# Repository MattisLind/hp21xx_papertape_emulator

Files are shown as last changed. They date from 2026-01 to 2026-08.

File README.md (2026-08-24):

# HP 21XX Paper Tape Emulator

The idea to this project come from this page: [newton.freehostia.com/hp](https://newton.freehostia.com/hp/). A simple PIC processor connected to the ubiquitous HP 12566 Microcircuit boards that provide 16 bits of general input and output with a simple handshake. The software interface is identical to the one used for the paper tape reader and paper tape punch. The interface originally used for punch and reader, 12597A is a +12V level interface which made them a bit harder to interface. The 12566A board which used just standard +5V signals was easier to work with and I had plenty of them.

So I thought I should make my own, but then I thought, why involve a PC. I could store the files I wished to download on a small SD-card and have a small display and a couple of buttons to interact with to select what file I wanted to download into the machine! And then there was this idea, why not make it work as a punch as well so that I can take the output from the HP computer and store it on a file that subsequently can be uploaded. Useful if one would try compiling some small program on it.

## Progress

Now I am able to both read files into the computer and punch from the computer. Here is a quick video showing when a Chess program is loaded into my HP 2100S.

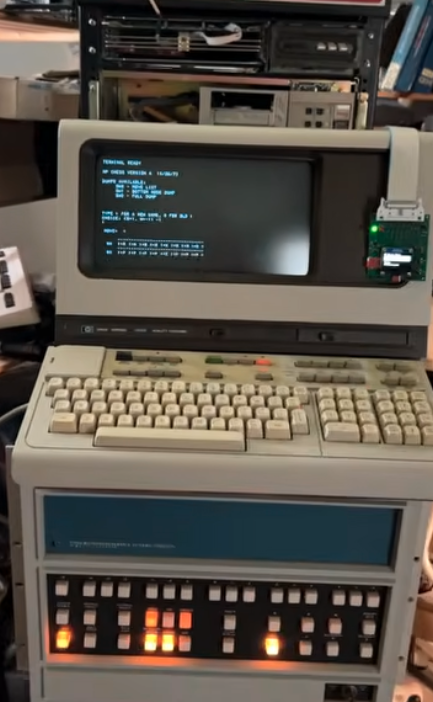
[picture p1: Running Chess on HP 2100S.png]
Watch the video (https://www.youtube.com/shorts/xUi1qgBoRDE)


Loading of the 72 k abolute binary files takes place when the red LED light up for a few seconds. It fills up the entire 32k Word memory space of the HP 2100.

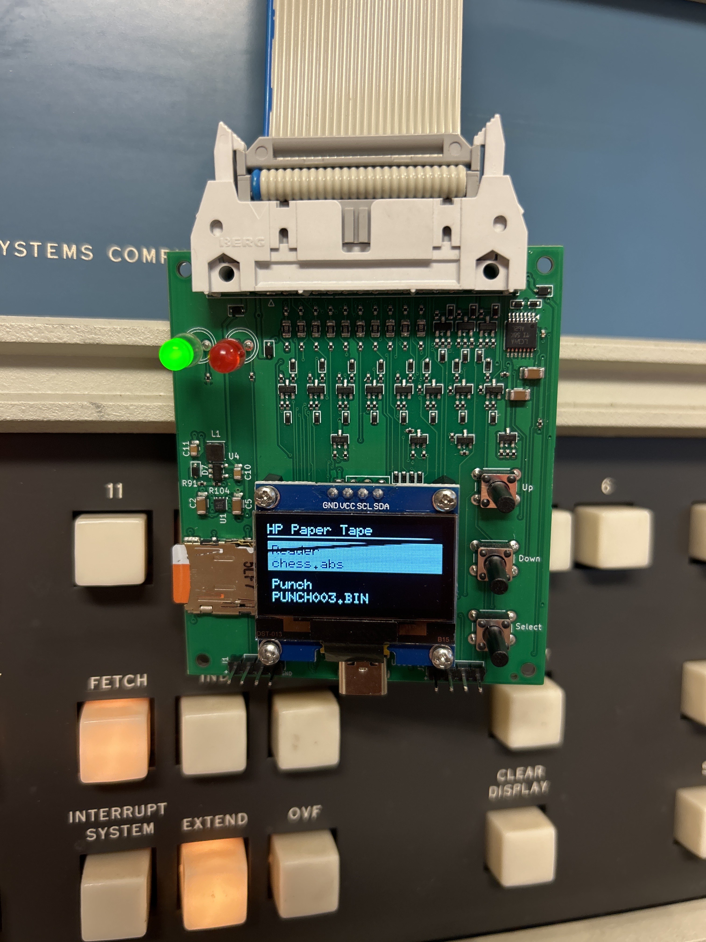
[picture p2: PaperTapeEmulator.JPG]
picture of the gadget


This is how the finished board came to look like. Three buttons, Up, Down and Select, and small 128x64 OLED panel to configure and control it. A Micro SD card for file storage and USB-C connector that can be used to power the device unless powered over the 26 pin ribbin connector. The green LED indicate power and the red LED indicate activity.

The UI is rather simple. Simply navigating up and down and press the select button. The main menu have two menu items, one to select the reader file and one select the punch file. Pressing select will get you to a file selct menu where the currently selected file is shown and where you can navigate to the file you want to select. Pressing select also exits back to the main menu. On the punch menu there are also an option to create a new file with a sequence number. If an existing file is selected it will append to that file.

Since there are only three buttons the UI also have special actions when pressing a button more than 4 seconds. A long press on the select menu brings up the configuration menu. In here you can set if signals are active high or active low. For 12566A and 12566B there are two board revsions which get you to choose from active high (POS TRUE) or active low (GND TRUE) data. The active high or low for hand shake signals are configurable on both these cards. The 12566C has all parameters configurable. You should check yoour board so that it matches the config you set in this menu. There is also an option to configure 12V signals or 5V signals. 5V is used for 12566 boards while 12V is used for 12597 boards. You cannot mix a 12566 board and a 12566 board and connect them simultaneously to the paper tape emulator. There are also certain variants of the 12597 board that have -12V signals. This type of board is not supported. Unless you convert the board to +12V.

If you long press on the Down button when in the main menu the currently selected file will be rewound to the beginning so that it can be read again.

If you long press on the Up button the USB MSC mode will be stated and all emulation is stopped. This will allow you to browse the contents from a host computer if the emulator is connected over USB-C. This feature is now active. The STM32F103 have a very small memory and it will take a while for the MCU to transfer big amounts to the host. Unfortunately it seems like at least Windows 10 wants to read about 16000 blocks from the disk when it is mounted. This takes quite some time and will ead to that the drive is not showing up active in the computer. Probably because the file system is 8Gb. I think that by making the partition smaller it will read less from the disk when moounting it. A 32 Meg partition will easily hold all the paper tapes you ever will use on a HP21xx machine.

## BOM

For all the surface mount components the BOM is among the production files in the kicad folder. Other than that the following hardware is needed to complete the emulator:

* [Screws  M2 5mm.  8 pcs](https://www.aliexpress.com/item/32768907028.html)
* [Nylon hex standoffs for the display are 6mm M2. 4 pcs](https://www.aliexpress.com/item/1005003577479911.html)
* [Nylon washers M2 5mm x 1mm high: 8 pcs.](https://www.aliexpress.com/item/1005008318320472.html)
* [Display is a OLED 128x64 with I2C Using SH1106 chip.](https://www.aliexpress.com/item/1005007451015054.html)
* [Buttons are 6x6 mm 13 mm high tactile buttons](https://www.aliexpress.com/item/1005002487399422.html)
* [Connector is Ampehnol FCI 71922-126LF](https://www.mouser.se/ProductDetail/649-71922-126LF)
* Red 5 mm LED
* Green 5 mm LED
* 4 pin header 2.54 mm for SWD and serial debugging port. 2 pcs.

## Connecting it to the HP machine 

The connector for the HP computer is a 48 pin 0.156 inch (3.96 mm) connector. EDAC and Sullins manufacture these.

I used a 26 pin ribbon connector in the emulator end and splitted that one in two 13 conductor halves going to one each 48 pin connector.

### Mods to supply 5V to the emulator

A good idea is to modify the 12566 and 12597 boards to supply 5V to the emulator. There are schottky diodes on the supply line internally on the emulator to avoid backpowering things so it should be safe to connect the punch and reader to different computers and also safe to have a PC connected to the USB simultaneously.

I modifed my 12566 boards to supply 5V on pin 20 since it is unused also on the 12597 boards this pin is unused.

### Reader
|Pin on 26 pin connector | Designator on the 26 pin connector | Pin on 48 pin connector for the 12566 board |HP designator on 12566 board | Pin on the 48 pin connector for the 12597 board | HP designator on 12597 board |
|----|-----|-----|----|----|----|
| 14 | NC  | NA  | NA | | |
| 15 | INCR | 22 |  DEVICE COMMAND  | AA  | Read |
| 16 | OUTFR | 23 | DEVICE FLAG | 23 | Feed Hole |
| 17 | OUT7 | 8  | Bit 7 | 8 | Bit 7 | 
| 18 | OUT6 | 7  | Bit 6 | 7 | Bit 6 |
| 19 | OUT5 | 6  | Bit 5 | 6 | Bit 5 | 
| 20 | OUT4 | 5  | Bit 4 | 5 | Bit 4 |
| 21 | OUT3 | 4  | Bit 3 | 4 | Bit 3 |
| 22 | OUT2 | 3  | Bit 2 | 3 | Bit 2 |
| 23 | OUT1 | 2  | Bit 1 | 2 | Bit 1 |
| 24 | OUT0 | 1  | Bit 0 | 1 | Bit 0 |
| 25 | GND  | 24 | Ground | 24 | Ground |
| 26 | +5V  | 20 | | 20 |  |

### Punch

Please note that the table below has been updated since I found errors in the table. If you built this cable already, please doublecheck the cable!

|Pin on 26 pin connector | Designator on the 26 pin connector | Pin on 48 pin connector for the 12566 board | HP designator on 12566 board |Pin on the 48 pin connector for the 12597 board | HP designator on 12597 board| 
|----|-----|-----|----|----|----|
| 1  | +5V | 20  | | 20 |  |
| 2  | GND | 24  | GROUND | 24 | Ground |
| 3  | IN0  | A  | BIT 0 | A  | Bit 0 |
| 4  | IN1  | B  | BIT 1 | B  | Bit 1 |
| 5  | IN2  | C  | BIT 2 | C  | Bit 2|
| 6  | IN3  | D  | BIT 3 | D  | Bit 3 |
| 7  | IN4  | E  | BIT 4 | E  | Bit 4 |
| 8  | IN5  | F  | BIT 5 | F | Bit 5 |
| 9 | IN6  | H  | BIT 6 | H  | Bit 6 |
| 10 | IN7 | J | BIT 7 | J | Bit 7 |
| 11  | OUTFP| 23 | DEVICE FLAG | 23 | Flag |
| 12  | INCP | 22  | DEVICE COMMAND | AA | Punch |
| 13 | PAPER_LOW | 6 | BIT 5 | 6 | Low Tape|

## Firmware

The firmware is built using the Arduino framework. <strike>I have been using the Maple based core adapted by Roger Clark: [Arduino_STM32](https://github.com/rogerclarkmelbourne/arduino_stm32). Follow the instructins and install this in your Arduino Environment.
In addition to that I have replaced the standard SDfat V2 library with a SDfat library that works with this core, [SDFat library by VictorPV](https://github.com/victorpv/SdFat), but still support long file names.

Then it is important to select this core under tools. Also select the correct target, STM32F103C8.</strike>

I now converted into using the standard core for STM32 on Arduino. The TinyUSB library has to be installed. In addition to that I downloaded and installed [TinyUSB-Arduino-STM32](https://github.com/code-fiasco/TinyUSB-Arduino-STM32?utm_source=chatgpt.com) for STM32 support. Please follow instructions in the repo.

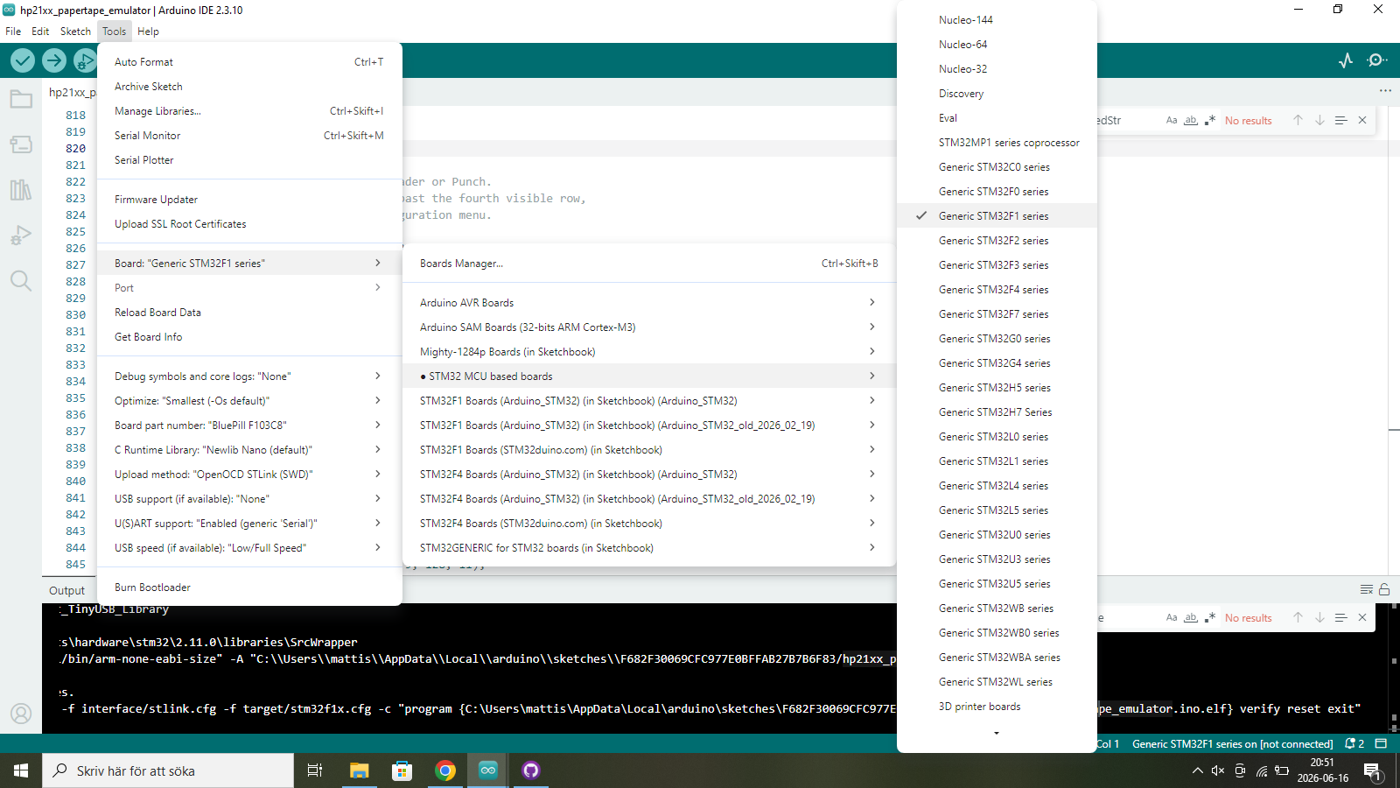
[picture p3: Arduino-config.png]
config


The picture above indicate the config needed. STM32F103 Bluepill. Please adapt dependning on download method. In the binaries folder there is a new binary that can be used directly.

Uploading takes place over SWD so a STM32 SWD dongle is required. Unfortunately there are no jumpers available on the board to allow download over the serial port. It can be patched. The BOOT0 pin is pulled down with a 10k resistor to ground but can be tied to +3.3V to achieve a high input. BOOT1/PB2 is currently in use as an output, PUSEL, which alread has a pull down to ground already. Jumpering BOOT0 like this would then allow to enter serial boot mode after reset. There is also no reset button so either a power cycle is required or attach an external button to the RESET input of the processor. Future version might add a BOOT0 jumper.

A new layout has been comitted to the repo that adds a jumper that allow setting BOOT0 high. Along with BOOT1 pulled low this will then let the MCU enter serial download mode.

Software to upload code via serial port is for example [stm32flash](https://github.com/FYSETC/stm32flash)

I have not tried serial boot mode myself so I cannot tell how to work with it. I always use the STM32 SWD dongle.

## Documentation

Here are some links to relevant HP document for the 12597 and 12566 boards:

* [12566B Micro circuit interface manual](https://bitsavers.org/pdf/hp/21xx/interfaces/12566.pdf)
* [12597A-002 Reader interface manual](https://www.bitsavers.org/pdf/hp/21xx/interfaces/12597A-002.pdf)
* [12597A-005 Punch interface manual](https://www.bitsavers.org/pdf/hp/21xx/interfaces/12597A-005.pdf)

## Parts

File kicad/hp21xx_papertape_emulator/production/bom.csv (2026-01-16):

Designator | Footprint | Quantity | Value | LCSC Part #
BRD1 | PinHeader_1x04_P2.54mm_Vertical | 1 | SSD1306
C1, C3 | 0402 | 2 | 20p | C1554
C10, C4, C6, C7, C8, C9 | 0402 | 6 | 100n | C1525
C2, C5 | 1206 | 2 | 4.7u | C29823
D1 | LED_D5.0mm | 1 | LED
D2 | LED_D5.0mm | 1 | 3.3V PWR
D3, D4 | D_SOD-323 | 2 | 1N5819WS | C191023
J1 | PinHeader_1x04_P2.54mm_Vertical | 1 | SWD
J2 | PinHeader_1x04_P2.54mm_Vertical | 1 | SERIAL
J3 | microSD_HC_Hirose_DM3AT-SF-PEJM5 | 1 | Micro_SD_Card_Det_Hirose_DM3AT
J4 | IDC-Header_2x10_P2.54mm_Latch_Horizontal | 1 | HP Microcircuit
R1, R2 | 0402 | 2 | 2k | C4109
R10, R26 | 0402 | 2 | 100k | C25741
R11, R13, R15, R17, R24, R27, R33, R35, R37 | 0402 | 9 | 330 | C25104
R12, R14, R16, R18, R25, R28, R34, R36, R38 | 0402 | 9 | 820 | C3015788
R19, R20, R21, R22, R23, R29, R30, R31, R32 | 0402 | 9 | 220 | C25091
R3, R4 | 0402 | 2 | 510 | C25123
R39 | 0603 | 1 | 1.8k | C4177
R40 | 0402 | 1 | 3.3k | C25890
R5 | 0402 | 1 | 1.5k | C25867
R6, R7 | 0402 | 2 | 22 | C25092
R8, R9 | 0402 | 2 | 5.1k | C25905
SW1 | SW_PUSH_6mm_H13mm | 1 | Select
SW2 | SW_PUSH_6mm_H13mm | 1 | Up
SW3 | SW_PUSH_6mm_H13mm | 1 | Down
U1 | WSON-6-1EP_2x2mm_P0.65mm_EP1x1.6mm | 1 | TLV75533PDRV | C2861750
U2 | LQFP-48_7x7mm_P0.5mm | 1 | STM32F103C8Tx | C8734
U3 | SOT-23-6 | 1 | USBLC6-2SC6 | C21713975
U4 | SOT-353_SC-70-5 | 1 | 74AHC1GU04 | C460485
U5 | TSSOP-20_4.4x6.5mm_P0.65mm | 1 | 74HCT245 | C6779
U6 | SOT-23-5 | 1 | 74LVC1G04 | C7827
U7 | TSSOP-20_4.4x6.5mm_P0.65mm | 1 | 74LVC245 | C7848
USB1 | HRO-TYPE-C-31-M-12 | 1 | HRO-TYPE-C-31-M-12 | C165948
Y1 | Crystal_SMD_5032-2Pin_5.0x3.2mm | 1 | 8MHz | C115962

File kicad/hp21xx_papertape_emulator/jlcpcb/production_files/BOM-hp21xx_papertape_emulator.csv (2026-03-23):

Comment | Designator | Footprint | LCSC | Quantity
1.5k | R5 | R_0402_1005Metric | C25867 | 1
1.8k | R39 | R_0603_1608Metric | C4177 | 1
100 | R10,R47,R48,R54,R57,R60,R63,R66,R69,R72,R75,R78,R81,R86,R88 | R_0402_1005Metric | C25076 | 15
100k | R19,R26,R55,R58,R61,R64,R67,R70,R73,R76,R79,R82,R85,R89,R93 | R_0402_1005Metric | C25741 | 15
100n | C4,C6,C7,C8,C9 | C_0402_1005Metric | C1525 | 5
10k | R1,R104,R2,R45,R49,R50,R51,R52,R56,R59,R62,R65,R68,R71,R74,R77,R80,R83 | R_0402_1005Metric | C25744 | 18
10uH | L1 | L_Sunlord_SWPA3010S | C2049730 | 1
1N5819WS | D3,D4,D5,D6,D7 | D_SOD-323 | C191023 | 5
1k | R100,R101,R102,R103,R12,R14,R16,R18,R25,R28,R34,R36,R38,R42,R46,R87,R94,R95,R96,R97,R98,R99 | R_0402_1005Metric | C11702 | 22
1u | C10,C11 | C_0805_2012Metric | C28323 | 2
20p | C1,C3 | C_0402_1005Metric | C1554 | 2
22 | R6,R7 | R_0402_1005Metric | C25092 | 2
220 | R20,R21,R22,R23,R29,R30,R31,R32,R43,R44 | R_0402_1005Metric | C25091 | 10
3.3k | R40 | R_0402_1005Metric | C25890 | 1
330 | R11,R13,R15,R17,R24,R27,R33,R35,R37,R41 | R_0805_2012Metric | C17630 | 10
4.7u | C12,C13,C2,C5 | C_1206_3216Metric | C29823 | 4
5.1k | R8,R9 | R_0402_1005Metric | C25905 | 2
510 | R3,R4 | R_0402_1005Metric | C25123 | 2
74LVC14 | U6 | TSSOP-14_4.4x5mm_P0.65mm | C7663 | 1
74LVC245 | U7 | TSSOP-20_4.4x6.5mm_P0.65mm | C7848 | 1
86.6k | R91 | R_0402_1005Metric | C19709 | 1
8MHz | Y1 | Crystal_SMD_5032-2Pin_5.0x3.2mm | C115962 | 1
AP3012 | U4 | SOT-23-5 | C102618 | 1
BAT54J | D10,D11,D12,D13,D14,D15,D16,D17,D18,D19,D20,D21,D22,D23,D24,D25,D26,D27,D28,D29,D8,D9 | D_SOD-523 | C51315114 | 22
BSS138 | Q1,Q10,Q11,Q13,Q14,Q2,Q3,Q4,Q5,Q6,Q7,Q8,Q9 | SOT-23 | C53113928 | 13
BSS84 | Q12,Q15 | SOT-23 | C82079 | 2
BZX584B5V1 | D30,D31,D32,D33,D34,D35,D36,D37,D38,D39 | D_SOD-523 | C968173 | 10
HRO-TYPE-C-31-M-12 | USB1 | HRO-TYPE-C-31-M-12 | C165948 | 1
Micro_SD_Card_Det_Hirose_DM3AT | J3 | microSD_HC_Hirose_DM3AT-SF-PEJM5 | C114218 | 1
STM32F103C8Tx | U2 | LQFP-48_7x7mm_P0.5mm | C8734 | 1
TLV75533PDRV | U1 | WSON-6-1EP_2x2mm_P0.65mm_EP1x1.6mm | C2861750 | 1
USBLC6-2SC6 | U3 | SOT-23-6 | C21713975 | 1

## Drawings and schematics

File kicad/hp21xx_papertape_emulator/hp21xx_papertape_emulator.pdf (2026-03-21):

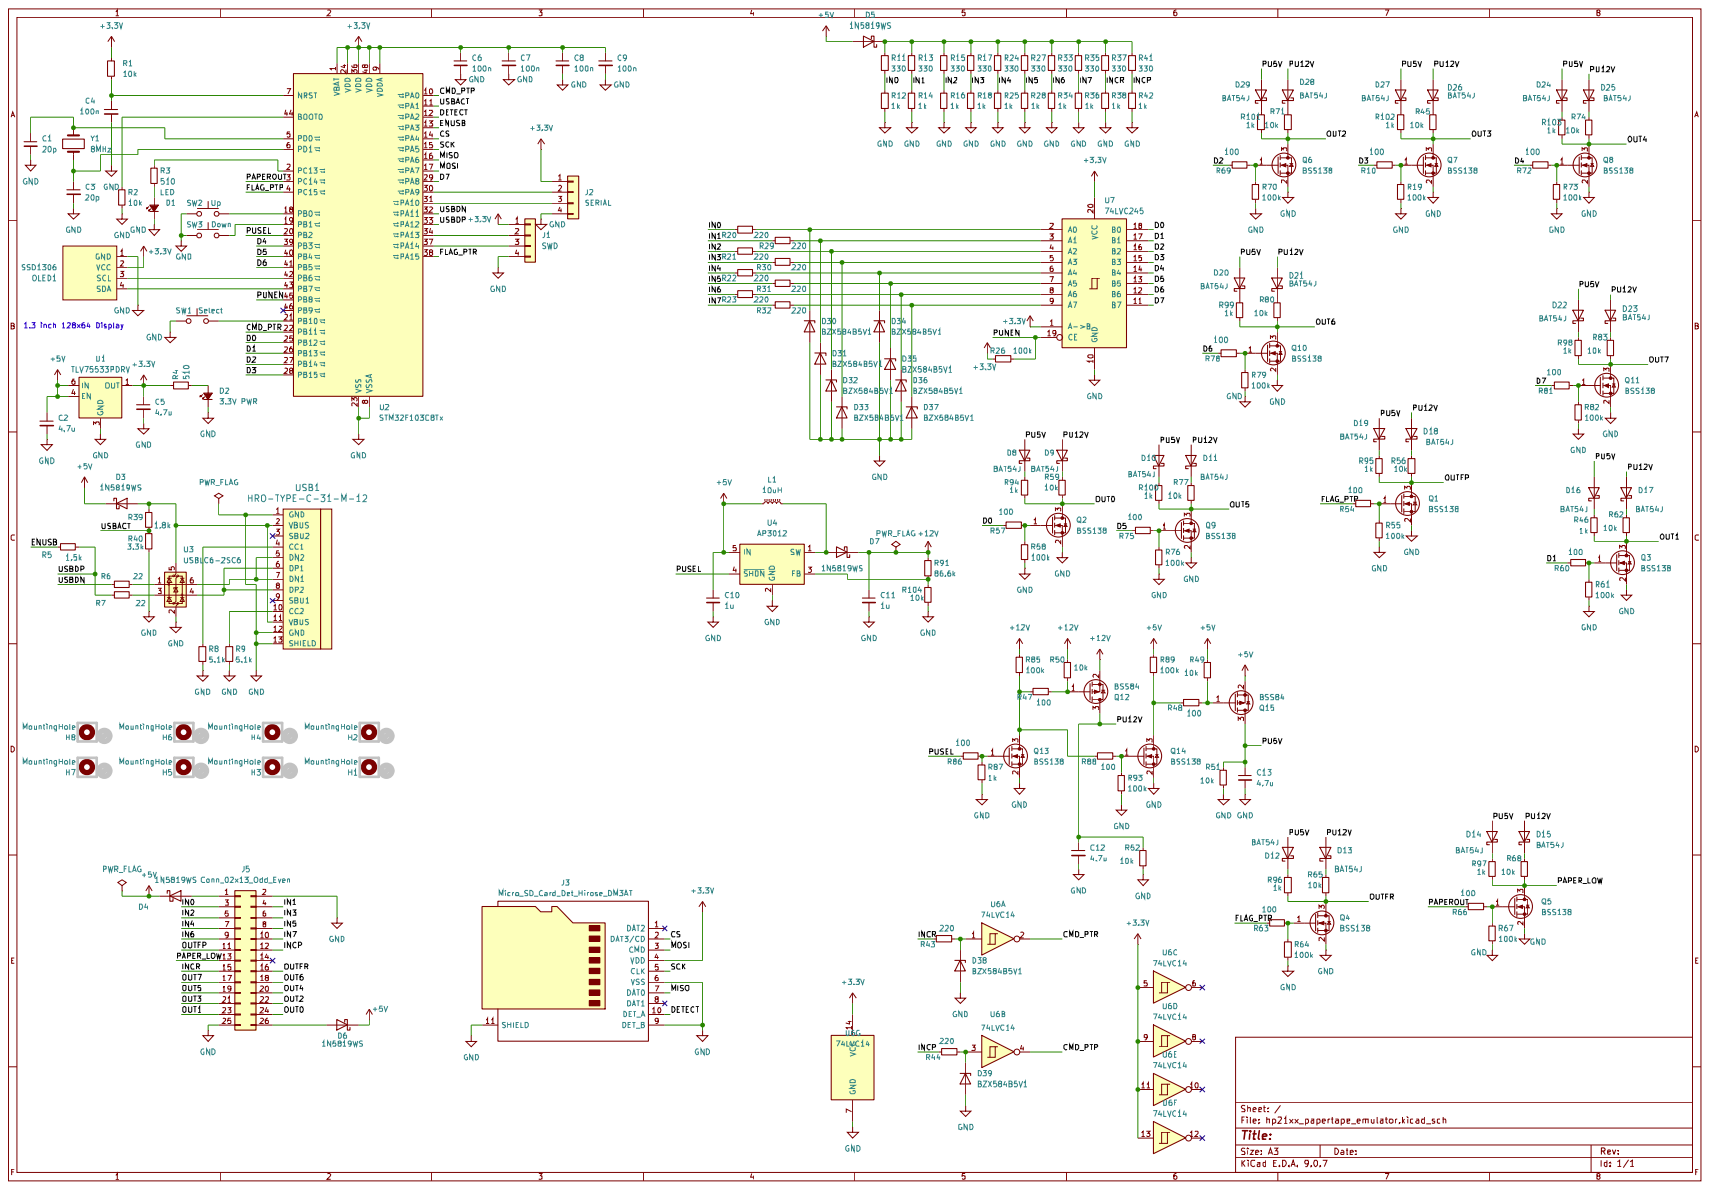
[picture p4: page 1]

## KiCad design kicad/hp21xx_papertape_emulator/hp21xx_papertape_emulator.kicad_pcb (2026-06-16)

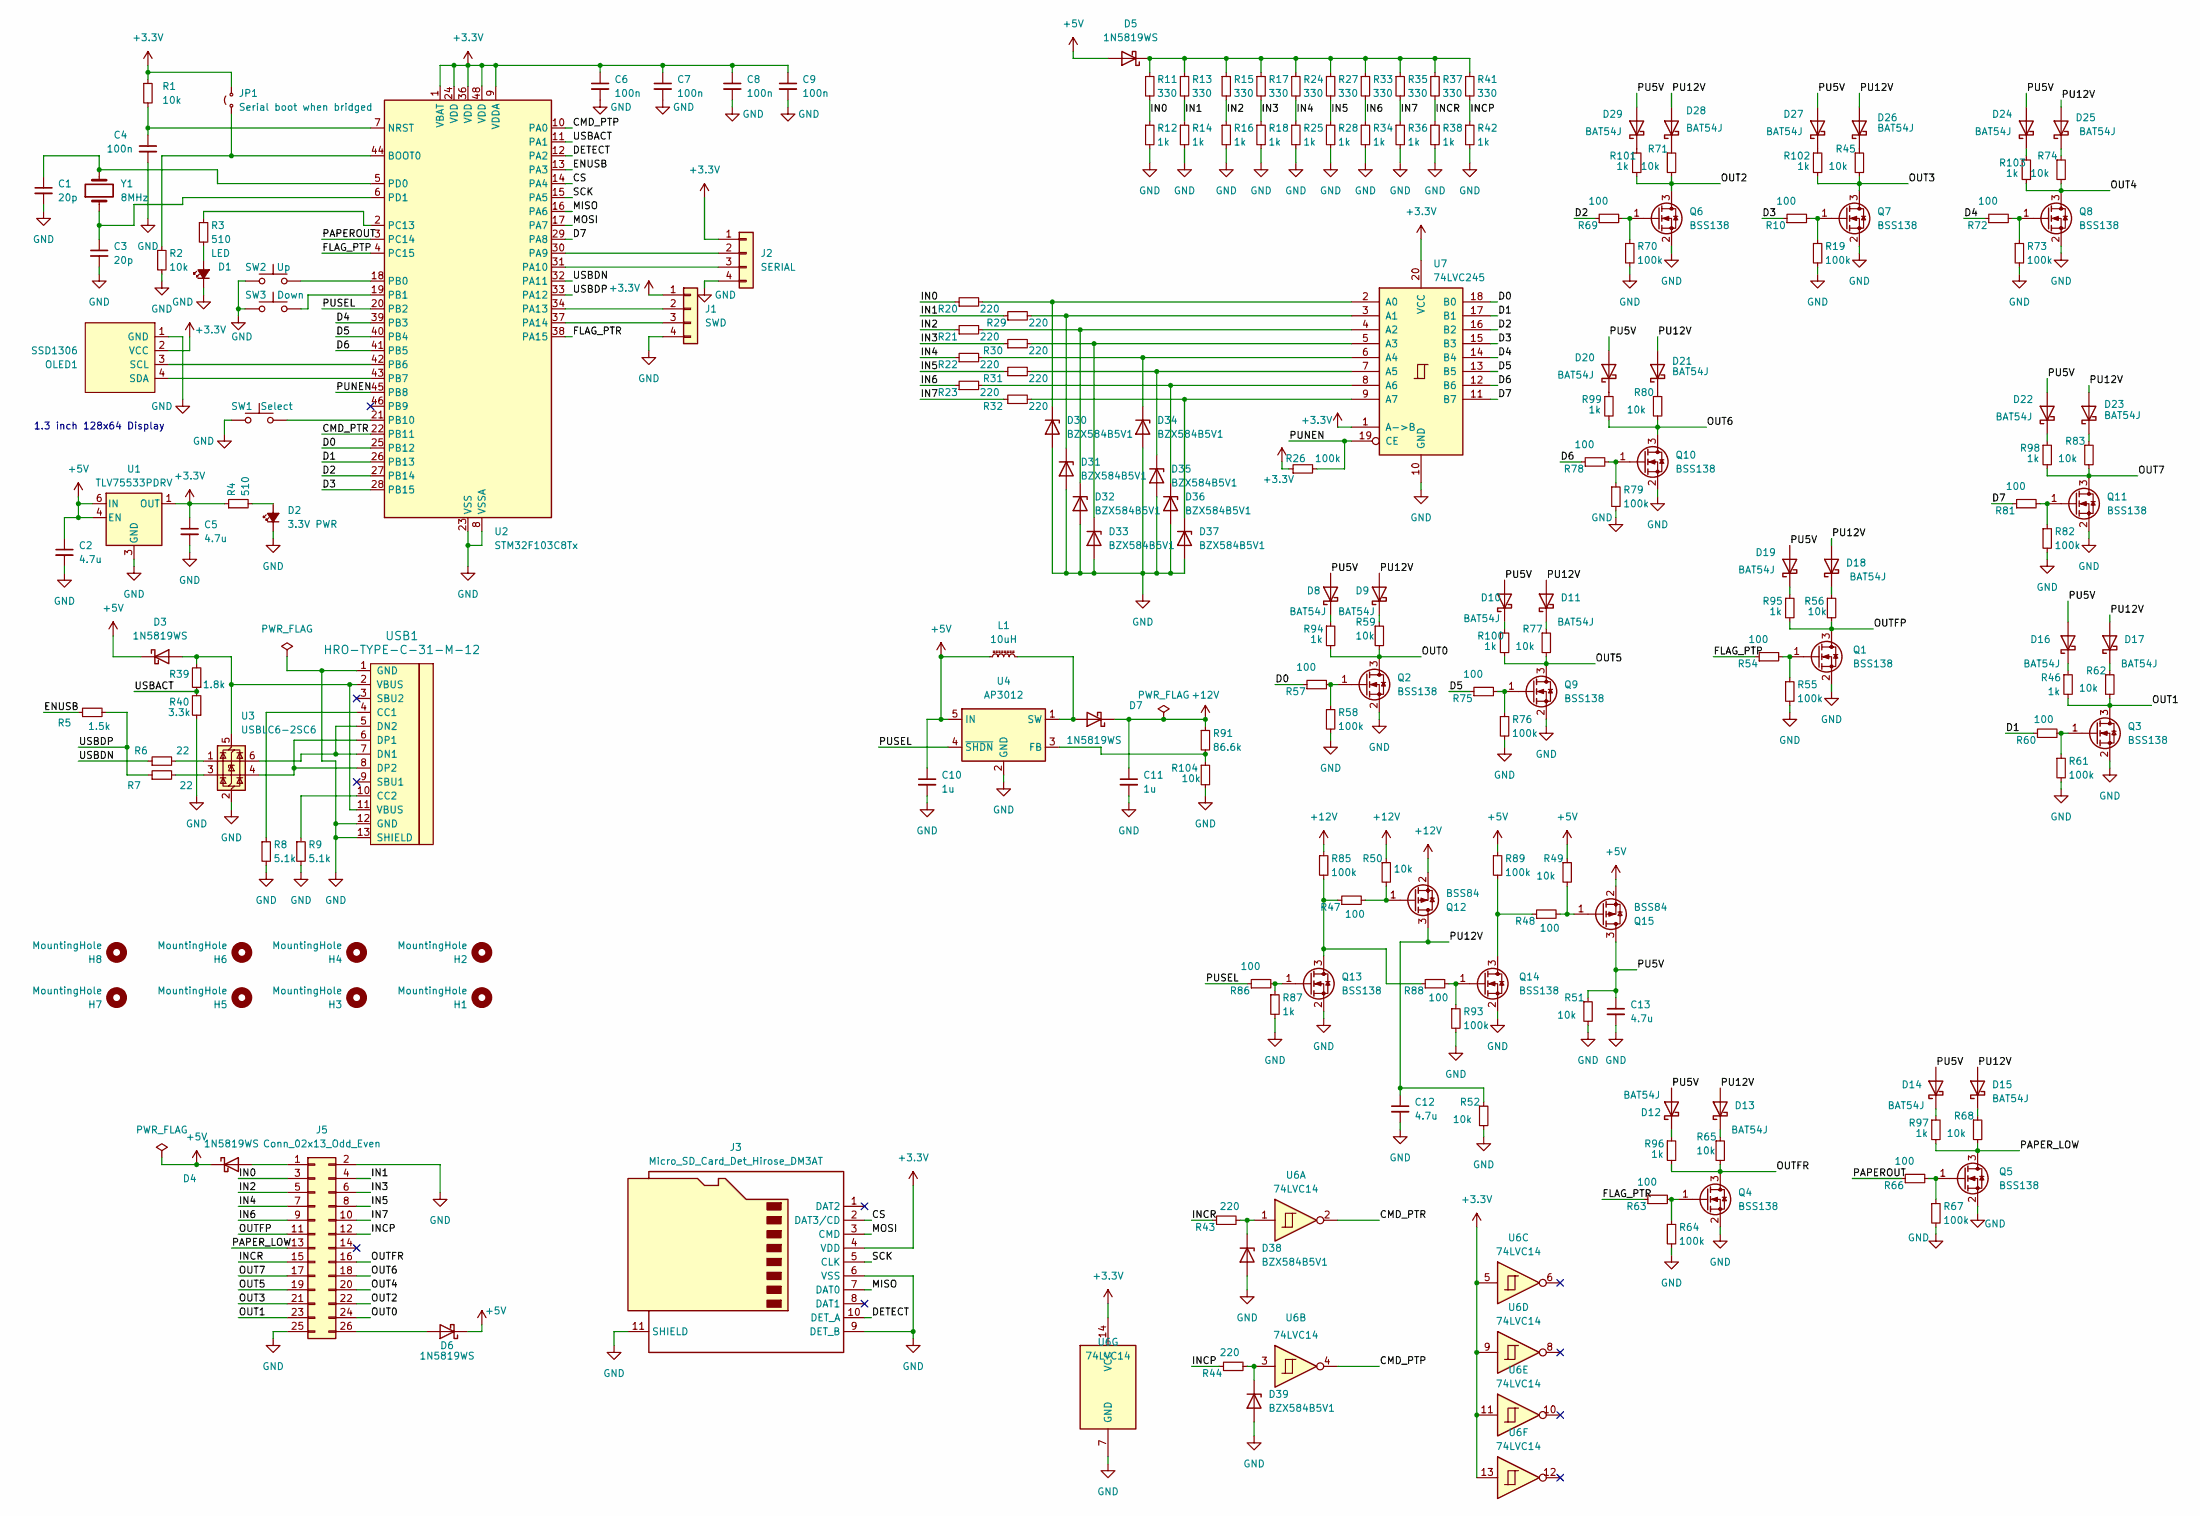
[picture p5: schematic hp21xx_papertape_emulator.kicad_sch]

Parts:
C1, C3: 20p; C_0402_1005Metric; LCSC C1554
C2, C5, C12, C13: 4.7u; C_1206_3216Metric; LCSC C29823
C4, C6, C7, C8, C9: 100n; C_0402_1005Metric; LCSC C1525
C10, C11: 1u; C_0805_2012Metric; LCSC C28323
D1: LED; LED_D5.0mm
D2: 3.3V PWR; LED_D5.0mm
D3, D4, D5, D6, D7: 1N5819WS; D_SOD-323; LCSC C191023
D8, D9, D10, D11, D12, D13, D14, D15, D16, D17, D18, D19, D20, D21, D22, D23, D24, D25, D26, D27, D28, D29: BAT54J; D_SOD-523; LCSC C51315114
D30, D31, D32, D33, D34, D35, D36, D37, D38, D39: BZX584B5V1; D_SOD-523; LCSC C968173
H1, H3, H5, H7: MountingHole; MountingHole_2.2mm_M2
H2, H4, H6, H8: MountingHole; MountingHole_2.5mm
J1: SWD; PinHeader_1x04_P2.54mm_Vertical
J2: SERIAL; PinHeader_1x04_P2.54mm_Vertical
J3: Micro_SD_Card_Det_Hirose_DM3AT; microSD_HC_Hirose_DM3AT-SF-PEJM5; LCSC C114218
J5: Conn_02x13_Odd_Even; IDC-Header_2x13_P2.54mm_Latch_Horizontal
JP1: Serial boot when bridged; PinHeader_1x02_P2.54mm_Vertical
L1: 10uH; L_Sunlord_SWPA3010S; LCSC C2049730
OLED1: SSD1306; PinHeader_1x04_P2.54mm_Vertical
Q1, Q2, Q3, Q4, Q5, Q6, Q7, Q8, Q9, Q10, Q11, Q13, Q14: BSS138; SOT-23; LCSC C53113928
Q12, Q15: BSS84; SOT-23; LCSC C41354933
R1, R2, R45, R49, R50, R51, R52, R56, R59, R62, R65, R68, R71, R74, R77, R80, R83, R104: 10k; R_0402_1005Metric; LCSC C25744
R3, R4: 510; R_0402_1005Metric; LCSC C25123
R5: 1.5k; R_0402_1005Metric; LCSC C25867
R6, R7: 22; R_0402_1005Metric; LCSC C25092
R8, R9: 5.1k; R_0402_1005Metric; LCSC C25905
R10, R47, R48, R54, R57, R60, R63, R66, R69, R72, R75, R78, R81, R86, R88: 100; R_0402_1005Metric; LCSC C25076
R11, R13, R15, R17, R24, R27, R33, R35, R37, R41: 330; R_0805_2012Metric; LCSC C17630
R12, R14, R16, R18, R25, R28, R34, R36, R38, R42, R46, R87, R94, R95, R96, R97, R98, R99, R100, R101, R102, R103: 1k; R_0402_1005Metric; LCSC C11702
R19, R26, R55, R58, R61, R64, R67, R70, R73, R76, R79, R82, R85, R89, R93: 100k; R_0402_1005Metric; LCSC C25741
R20, R21, R22, R23, R29, R30, R31, R32, R43, R44: 220; R_0402_1005Metric; LCSC C25091
R39: 1.8k; R_0603_1608Metric; LCSC C4177
R40: 3.3k; R_0402_1005Metric; LCSC C25890
R91: 86.6k; R_0402_1005Metric; LCSC C19709
SW1: Select; SW_PUSH_6mm_H13mm
SW2: Up; SW_PUSH_6mm_H13mm
SW3: Down; SW_PUSH_6mm_H13mm
U1: TLV75533PDRV; WSON-6-1EP_2x2mm_P0.65mm_EP1x1.6mm; LCSC C2861750
U2: STM32F103C8Tx; LQFP-48_7x7mm_P0.5mm; LCSC C8734
U3: USBLC6-2SC6; SOT-23-6; LCSC C21713975
U4: AP3012; SOT-23-5; LCSC C102618
U6: 74LVC14; TSSOP-14_4.4x5mm_P0.65mm; LCSC C7663
U7: 74LVC245; TSSOP-20_4.4x6.5mm_P0.65mm; LCSC C7848
USB1: HRO-TYPE-C-31-M-12; MPN TYPE-C-31-M-12; LCSC C165948
Y1: 8MHz; Crystal_SMD_5032-2Pin_5.0x3.2mm; LCSC C115962

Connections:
+3.3V: C5.1, C6.1, C7.1, C8.1, C9.1, J1.1, J2.1, J3.4 (VDD), JP1.2 (B), OLED1.2 (VCC), R1.1, R4.1, R26.1, U1.1 (OUT), U2.1 (VBAT), U2.9 (VDDA), U2.24 (VDD), U2.36 (VDD), U2.48 (VDD), U6.5, U6.9, U6.11, U6.13, U6.14 (VCC), U7.1 (A->B), U7.20 (VCC); also elsewhere on the board
+5V: C2.1, C10.1, D3.1 (K), D4.1 (K), D5.2 (A), D6.1 (K), L1.1, Q15.2 (S), R49.1, R89.1, U1.4 (EN), U1.6 (IN), U4.5 (IN)
+12V: C11.1, D7.1 (K), Q12.2 (S), R50.1, R85.1, R91.1
/CMD_PTP: U2.10 (PA0), U6.4
/CMD_PTR: U2.22 (PB11), U6.2
/CS: J3.2 (DAT3/CD), U2.14 (PA4)
/D0: R57.1, U2.25 (PB12), U7.18 (B0)
/D1: R60.1, U2.26 (PB13), U7.17 (B1)
/D2: R69.1, U2.27 (PB14), U7.16 (B2)
/D3: R10.1, U2.28 (PB15), U7.15 (B3)
/D4: R72.1, U2.39 (PB3), U7.14 (B4)
/D5: R75.1, U2.40 (PB4), U7.13 (B5)
/D6: R78.1, U2.41 (PB5), U7.12 (B6)
/D7: R81.1, U2.29 (PA8), U7.11 (B7)
/DETECT: J3.10 (DET_A), U2.12 (PA2)
/ENUSB: R5.1, U2.13 (PA3)
/FLAG_PTP: R54.1, U2.4 (PC15)
/FLAG_PTR: R63.1, U2.38 (PA15)
/IN0: J5.3, R11.2, R12.1, R20.1
/IN1: J5.4, R13.2, R14.1, R29.1
/IN2: J5.5, R15.2, R16.1, R21.1
/IN3: J5.6, R17.2, R18.1, R30.1
/IN4: J5.7, R22.1, R24.2, R25.1
/IN5: J5.8, R27.2, R28.1, R31.1
/IN6: J5.9, R23.1, R33.2, R34.1
/IN7: J5.10, R32.1, R35.2, R36.1
/INCP: J5.12, R41.2, R42.1, R44.1
/INCR: J5.15, R37.2, R38.1, R43.1
/MISO: J3.7 (DAT0), U2.16 (PA6)
/MOSI: J3.3 (CMD), U2.17 (PA7)
/OUT0: J5.24, Q2.3 (D), R59.2, R94.2
/OUT1: J5.23, Q3.3 (D), R46.2, R62.2
/OUT2: J5.22, Q6.3 (D), R71.2, R101.2
/OUT3: J5.21, Q7.3 (D), R45.2, R102.2
/OUT4: J5.20, Q8.3 (D), R74.2, R103.2
/OUT5: J5.19, Q9.3 (D), R77.2, R100.2
/OUT6: J5.18, Q10.3 (D), R80.2, R99.2
/OUT7: J5.17, Q11.3 (D), R83.2, R98.2
/OUTFP: J5.11, Q1.3 (D), R56.2, R95.2
/OUTFR: J5.16, Q4.3 (D), R65.2, R96.2
/PAPEROUT: R66.1, U2.3 (PC14)
/PAPER_LOW: J5.13, Q5.3 (D), R68.2, R97.2
/PU5V: C13.1, D8.2 (A), D10.2 (A), D12.2 (A), D14.2 (A), D16.2 (A), D19.2 (A), D20.2 (A), D22.2 (A), D24.2 (A), D27.2 (A), D29.2 (A), Q15.3 (D), R51.1
/PU12V: C12.1, D9.2 (A), D11.2 (A), D13.2 (A), D15.2 (A), D17.2 (A), D18.2 (A), D21.2 (A), D23.2 (A), D25.2 (A), D26.2 (A), D28.2 (A), Q12.3 (D), R52.1
/PUNEN: R26.2, U2.45 (PB8), U7.19 (CE)
/PUSEL: R86.1, U2.20 (PB2), U4.4 (~SHDN)
/SCK: J3.5 (CLK), U2.15 (PA5)
/USBACT: R39.1, R40.2, U2.11 (PA1)
/USBDN: R6.1, U2.32 (PA11)
/USBDP: R5.2, R7.1, U2.33 (PA12)
GND: C1.2, C2.2, C3.2, C4.2, C5.2, C6.2, C7.2, C8.2, C9.2, C10.2, C11.2, C12.2, C13.2, D1.1 (K), D2.1 (K), D30.2 (A), D31.2 (A), D32.2 (A), D33.2 (A), D34.2 (A), D35.2 (A), D36.2 (A), D37.2 (A), D38.2 (A), D39.2 (A), J1.4, J2.4, J3.6 (VSS), J3.9 (DET_B), J3.11 (SHIELD), J5.2, J5.25, OLED1.1 (GND), Q1.2 (S), Q2.2 (S), Q3.2 (S), Q4.2 (S), Q5.2 (S), Q6.2 (S), Q7.2 (S), Q8.2 (S), Q9.2 (S), Q10.2 (S), Q11.2 (S), Q13.2 (S), Q14.2 (S), R2.2, R8.2, R9.2, R12.2, R14.2, R16.2, R18.2, R19.2, R25.2, R28.2, R34.2, R36.2, R38.2, R40.1, R42.2, R51.2, R52.2, R55.2, R58.2, R61.2, R64.2, R67.2, R70.2, R73.2, R76.2, R79.2, R82.2, R87.2, R93.2, R104.2, SW1.1, SW2.1, SW3.1, U1.3 (GND), U1.7 (GND), U2.8 (VSSA), U2.23 (VSS), U2.35 (VSS), U2.47 (VSS), U3.2 (GND), U4.2 (GND), U6.7 (GND), U7.10 (GND), USB1.1 (GND), USB1.12 (GND), USB1.13 (SHIELD)
unnamed: D1.2 (A), R3.2
unnamed: D2.2 (A), R4.2
unnamed: D3.2 (A), R39.2, U3.5 (VBUS), USB1.2 (VBUS), USB1.11 (VBUS)
unnamed: D4.2 (A), J5.1
unnamed: D5.1 (K), R11.1, R13.1, R15.1, R17.1, R24.1, R27.1, R33.1, R35.1, R37.1, R41.1
unnamed: D6.2 (A), J5.26
unnamed: D7.2 (A), L1.2, U4.1 (SW)
unnamed: D8.1 (K), R94.1
unnamed: D9.1 (K), R59.1
unnamed: D10.1 (K), R100.1
unnamed: D11.1 (K), R77.1
unnamed: D12.1 (K), R96.1
unnamed: D13.1 (K), R65.1
unnamed: D14.1 (K), R97.1
unnamed: D15.1 (K), R68.1
unnamed: D16.1 (K), R46.1
unnamed: D17.1 (K), R62.1
unnamed: D18.1 (K), R56.1
unnamed: D19.1 (K), R95.1
unnamed: D20.1 (K), R99.1
unnamed: D21.1 (K), R80.1
unnamed: D22.1 (K), R98.1
unnamed: D23.1 (K), R83.1
unnamed: D24.1 (K), R103.1
unnamed: D25.1 (K), R74.1
unnamed: D26.1 (K), R45.1
unnamed: D27.1 (K), R102.1
unnamed: D28.1 (K), R71.1
unnamed: D29.1 (K), R101.1
unnamed: D30.1 (K), R20.2, U7.2 (A0)
unnamed: D31.1 (K), R29.2, U7.3 (A1)
unnamed: D32.1 (K), R21.2, U7.4 (A2)
unnamed: D33.1 (K), R30.2, U7.5 (A3)
unnamed: D34.1 (K), R22.2, U7.6 (A4)
unnamed: D35.1 (K), R31.2, U7.7 (A5)
unnamed: D36.1 (K), R23.2, U7.8 (A6)
unnamed: D37.1 (K), R32.2, U7.9 (A7)
unnamed: D38.1 (K), R43.2, U6.1
unnamed: D39.1 (K), R44.2, U6.3
unnamed: J1.2, U2.34 (PA13)
unnamed: J1.3, U2.37 (PA14)
unnamed: J2.2, U2.30 (PA9)
unnamed: J2.3, U2.31 (PA10)
unnamed 94: JP1.1 (A), R2.1, U2.44 (BOOT0); also elsewhere on the board
unnamed: OLED1.3 (SCL), U2.42 (PB6)
unnamed: OLED1.4 (SDA), U2.43 (PB7)
unnamed: Q1.1 (G), R54.2, R55.1
unnamed: Q2.1 (G), R57.2, R58.1
unnamed: Q3.1 (G), R60.2, R61.1
unnamed: Q4.1 (G), R63.2, R64.1
unnamed: Q5.1 (G), R66.2, R67.1
unnamed: Q6.1 (G), R69.2, R70.1
unnamed: Q7.1 (G), R10.2, R19.1
unnamed: Q8.1 (G), R72.2, R73.1
unnamed: Q9.1 (G), R75.2, R76.1
unnamed: Q10.1 (G), R78.2, R79.1
unnamed: Q11.1 (G), R81.2, R82.1
unnamed: Q12.1 (G), R47.2, R50.2
unnamed: Q13.3 (D), R47.1, R85.2, R88.1
unnamed: Q13.1 (G), R86.2, R87.1
unnamed: Q14.3 (D), R48.1, R89.2
unnamed: Q14.1 (G), R88.2, R93.1
unnamed: Q15.1 (G), R48.2, R49.2
unnamed: R6.2, U3.1 (I/O1)
unnamed: R7.2, U3.3 (I/O2)
unnamed: C4.1, R1.2, U2.7 (NRST)
unnamed: SW2.2, U2.18 (PB0)
unnamed: SW3.2, U2.19 (PB1)
unnamed: SW1.2, U2.21 (PB10)
unnamed: R3.1, U2.2 (PC13)
unnamed: C1.1, U2.5 (PD0), Y1.2
unnamed: C3.1, U2.6 (PD1), Y1.1
unnamed: R91.2, R104.1, U4.3 (FB)
unnamed: R8.1, USB1.4 (CC1)
unnamed: R9.1, USB1.10 (CC2)
unnamed: U3.6 (I/O1), USB1.5 (DN2), USB1.7 (DN1)
unnamed: U3.4 (I/O2), USB1.6 (DP1), USB1.8 (DP2)

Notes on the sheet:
1.3 inch 128x64 Display

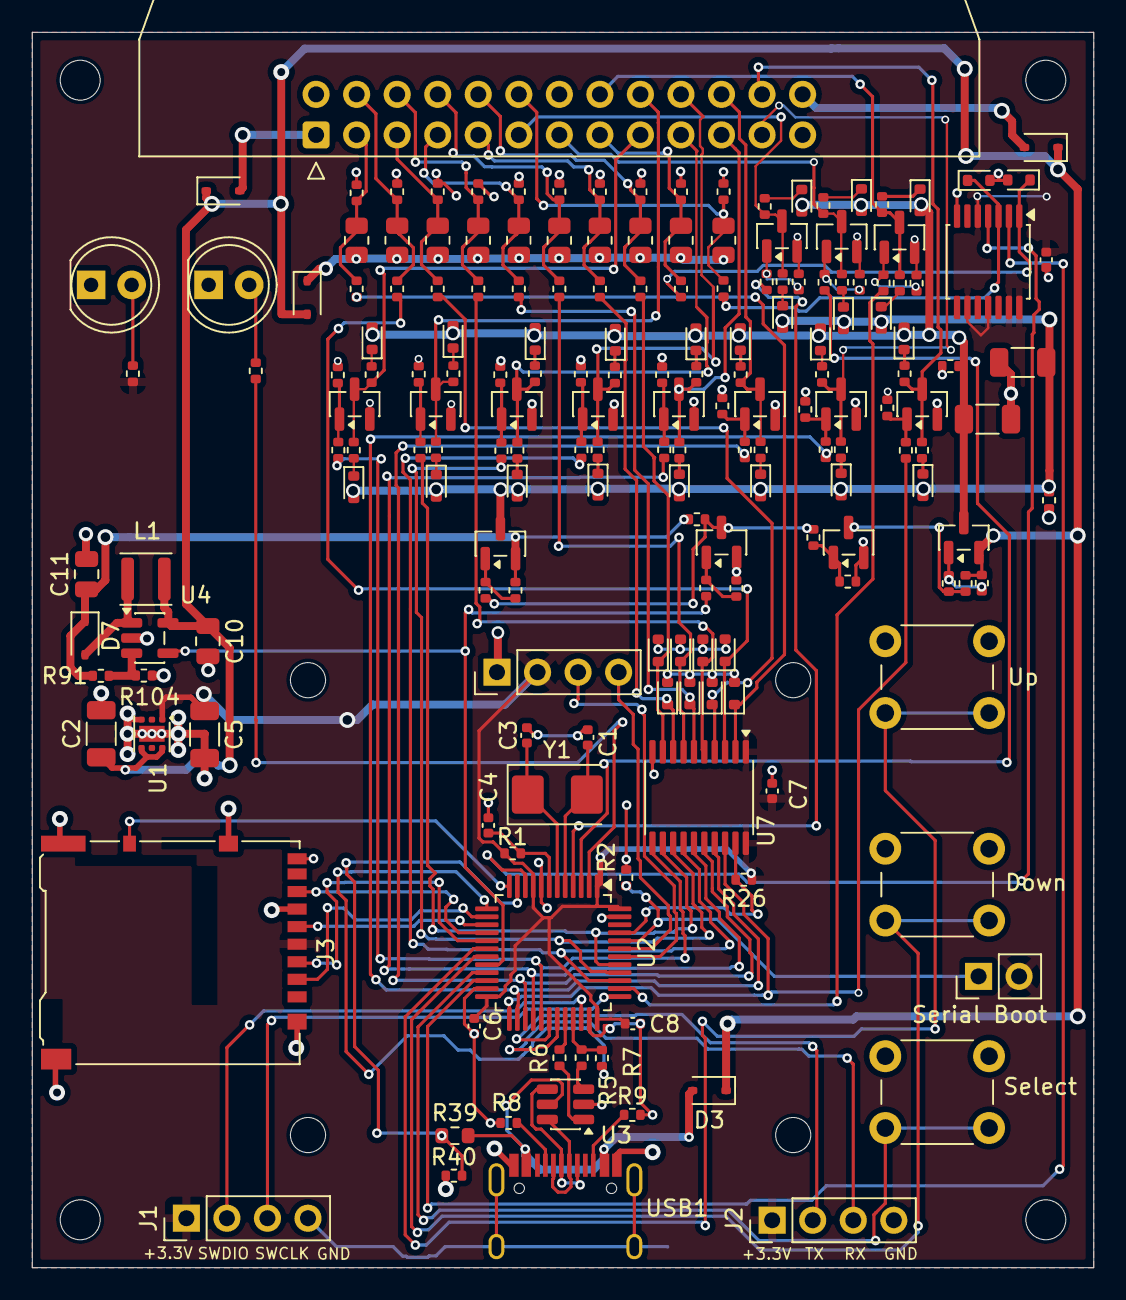
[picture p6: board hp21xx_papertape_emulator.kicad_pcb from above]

Board: 2 copper layers, 66.5 x 77.4 mm, 193 parts (0 on the bottom side), 128 nets.

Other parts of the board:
Serial Boot: Serial boot when bridged; PinHeader_1x02_P2.54mm_Vertical

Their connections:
+3.3V: Serial Boot.2 (B); also elsewhere on the board
unnamed 94: Serial Boot.1 (A); also elsewhere on the board

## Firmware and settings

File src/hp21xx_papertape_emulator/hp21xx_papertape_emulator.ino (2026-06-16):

/*
  HP Paper Tape Reader/Punch Emulator
  Target: STM32F103C8 using official STM32duino Arduino_Core_STM32 + TinyUSB

  Notes:
  - This is a first complete firmware structure based on the supplied requirements.
  - USB MSC uses TinyUSB/Adafruit TinyUSB style callbacks.
  - All timing-critical paper tape handshakes avoid Serial printing and GUI updates.
  - JTAG is disabled in setup() so PA15, PB3 and PB4 can be used as GPIO.
*/

#include <Arduino.h>
#include <Wire.h>
#include <SPI.h>
//#include <SD.h>
#include <SdFat.h>
#include <Adafruit_TinyUSB.h>
#include <U8g2lib.h>

#define DEBUG 0

#if DEBUG
  #define DBG_BEGIN() Serial1.begin(115200)
  #define DBG_PRINT(x) Serial1.print(x)
  #define DBG_PRINTLN(x) Serial1.println(x)
#else
  #define DBG_BEGIN()
  #define DBG_PRINT(x)
  #define DBG_PRINTLN(x)
#endif

SdFat SD;

// Forward declarations used by the TinyUSB callbacks.
static bool checkSdPresent(void);
static bool beginSdFilesystem(void);
static void blinkActivity(void);
// -----------------------------------------------------------------------------
// Pin mapping from requirements
// -----------------------------------------------------------------------------

static const uint8_t PIN_BTN_UP      = PB0;
static const uint8_t PIN_BTN_DOWN    = PB1;
static const uint8_t PIN_BTN_SELECT  = PB10;

static const uint8_t PIN_SD_CS       = PA4;
static const uint8_t PIN_SD_DETECT   = PA2;  // Active low, pull-up required

static const uint8_t PIN_USB_VBUS    = PA1;  // High when USB VBUS is present
static const uint8_t PIN_USB_PULLUP  = PA3;  // Drive high to connect USB pull-up circuit

static const uint8_t PIN_ACTIVITY_LED = PC13;

static const uint8_t PIN_BUS_DIR      = PB8;  // Active low: low enables external host-to-device buffer for punch input
static const uint8_t PIN_LEVEL_SELECT = PB2;  // High = 12 V interface, Low = 5 V interface
static const uint8_t PIN_OUT_OF_TAPE  = PC14;

static const uint8_t PIN_READER_CMD   = PB11;
static const uint8_t PIN_READER_ACK   = PA15;

static const uint8_t PIN_PUNCH_CMD    = PA0;
static const uint8_t PIN_PUNCH_ACK    = PC15;

static const uint8_t DATA_PINS[8] = {
  PB12, // D0
  PB13, // D1
  PB14, // D2
  PB15, // D3
  PB3,  // D4, requires JTAG disabled
  PB4,  // D5, requires JTAG disabled
  PB5,  // D6
  PA8   // D7
};

// -----------------------------------------------------------------------------
// USB MSC
// -----------------------------------------------------------------------------

// TinyUSB MSC exposes the SD card as raw 512-byte sectors.  While MSC is active,
// the firmware must not use FAT/SdFat file APIs.  Only raw sector access in the
// callbacks is allowed.
Adafruit_USBD_MSC usb_msc;

static uint32_t usbMscSectorCount = 0;
static bool usbMscConfigured = false;
static volatile uint32_t usbMscReadCount = 0;
static volatile uint32_t usbMscWriteCount = 0;

static int32_t usbMscReadCallback(uint32_t lba, void *buffer, uint32_t bufsize) {
  // Read raw sectors requested by the host.
  // TinyUSB uses 512-byte logical blocks for MSC.
  uint32_t numSectors = bufsize / 512UL;

  blinkActivity();
  usbMscReadCount++;

  if (!SD.card()->readSectors(lba, (uint8_t *)buffer, numSectors)) {
    return -1;
  }

  return (int32_t)bufsize;
}

static int32_t usbMscWriteCallback(uint32_t lba, uint8_t *buffer, uint32_t bufsize) {
  // Write raw sectors requested by the host.
  // Do not touch FAT here; the host owns the filesystem in MSC mode.
  uint32_t numSectors = bufsize / 512UL;

  blinkActivity();
  usbMscWriteCount++;

  if (!SD.card()->writeSectors(lba, buffer, numSectors)) {
    return -1;
  }

  return (int32_t)bufsize;
}

static void usbMscFlushCallback(void) {
  // Flush pending SD-card writes after host write commands.
  SD.card()->syncDevice();
}

// -----------------------------------------------------------------------------
// Display
// -----------------------------------------------------------------------------

// SH1106 128x64 over hardware I2C on PB6/PB7 for STM32F103 I2C1.
U8G2_SH1106_128X64_NONAME_F_HW_I2C display(U8G2_R0, U8X8_PIN_NONE);

// -----------------------------------------------------------------------------
// Configuration
// -----------------------------------------------------------------------------

static const char *CONFIG_FILE = "/ptape.cfg";
static const char *TAPE_DIR    = "/tapes";  // Shared directory for both reader input and punched output

#define MAX_FILES 32
#define MAX_NAME_LEN 64

struct InterfaceSettings {
  bool commandActiveHigh;
  bool ackPulseActiveHigh;
  bool dataActiveHigh;
};

struct AppConfig {
  InterfaceSettings reader;
  InterfaceSettings punch;
  bool use12V;
  char selectedReader[MAX_NAME_LEN];
  char selectedPunch[MAX_NAME_LEN];
};

AppConfig config;

// -----------------------------------------------------------------------------
// Runtime state
// -----------------------------------------------------------------------------

enum UiMode {
  UI_MAIN,
  UI_SECTION_FILES,
  UI_CONFIG,
  UI_USB_MSC
};

enum Section {
  SECTION_READER,
  SECTION_PUNCH
};

UiMode uiMode = UI_MAIN;
Section activeSection = SECTION_READER;
uint8_t mainCursor = 0;
uint8_t fileCursor = 0;
uint8_t configCursor = 0;

char readerFiles[MAX_FILES][MAX_NAME_LEN];
char punchFiles[MAX_FILES][MAX_NAME_LEN];
uint8_t readerFileCount = 0;
uint8_t punchFileCount = 0;

File32 readerFile;
File32 punchFile;
bool sdPresent = false;
bool emulatorEnabled = false;
bool usbMscEnabled = false;

unsigned long activityLedOffAtMs = 0;

// -----------------------------------------------------------------------------
// Button handling
// -----------------------------------------------------------------------------

struct ButtonState {
  uint8_t pin;
  bool stablePressed;
  bool lastRawPressed;
  unsigned long lastChangeMs;
  unsigned long pressedAtMs;
  bool longReported;
};

ButtonState buttons[3] = {
  { PIN_BTN_UP, false, false, 0, 0, false },
  { PIN_BTN_DOWN, false, false, 0, 0, false },
  { PIN_BTN_SELECT, false, false, 0, 0, false }
};

static const unsigned long DEBOUNCE_MS = 30;
static const unsigned long LONG_PRESS_MS = 4000;

// -----------------------------------------------------------------------------
// Low-level helpers
// -----------------------------------------------------------------------------

static bool isActive(bool signalLevel, bool activeHigh) {
  // Compare the physical input level with the configured active polarity.
  return activeHigh ? !signalLevel : signalLevel;
}

static void writeConfiguredLevel(uint8_t pin, bool active, bool activeHigh) {
  // Convert a logical active/inactive state into the configured physical level.
  digitalWrite(pin, active == activeHigh ? LOW : HIGH);
}

static void setDataBusInput(void) {
  // Put all shared data bus pins in high-impedance input mode.
  for (uint8_t i = 0; i < 8; i++) {
    pinMode(DATA_PINS[i], INPUT);
  }
}

static void setDataBusOutput(void) {
  // Put all shared data bus pins in push-pull output mode.
  for (uint8_t i = 0; i < 8; i++) {
    pinMode(DATA_PINS[i], OUTPUT);
  }
}

static void writeDataBus(uint8_t value, bool activeHigh) {
  // Write one byte to D0..D7, least significant bit first.
  for (uint8_t i = 0; i < 8; i++) {
    bool tmp = (value & (1U << i));
    digitalWrite(DATA_PINS[i], tmp == activeHigh ? HIGH : LOW);
  }
}

static uint8_t readDataBus(bool activeHigh) {
  // Read one byte from D0..D7, least significant bit first.
  uint8_t value = 0;
  uint8_t complementor = activeHigh?0x00:0xff;
  for (uint8_t i = 0; i < 8; i++) {
    if (digitalRead(DATA_PINS[i]) == HIGH) {
      value |= (1U << i);
    }
  }
  
  return value^complementor;
}

static void pulseAck(uint8_t pin, bool activeHigh) {
  // Generate an approximately 1 microsecond acknowledgement pulse.
  writeConfiguredLevel(pin, true, activeHigh);
  delayMicroseconds(5);
  writeConfiguredLevel(pin, false, activeHigh);
}

static void blinkActivity(void) {
  // PC13 is often wired as active-low LED on Blue Pill style boards.
  // If your hardware is active-high, invert these two writes.
  digitalWrite(PIN_ACTIVITY_LED, HIGH);
  activityLedOffAtMs = millis() + 1;
}

static void serviceActivityLed(void) {
  // Turn the activity LED off after a short visible blink time.
  if (activityLedOffAtMs != 0 && millis() >= activityLedOffAtMs) {
    digitalWrite(PIN_ACTIVITY_LED, LOW);
    activityLedOffAtMs = 0;
  }
}

static void applyLevelSelect(void) {
  // The spec says high selects 12 V and low selects 5 V.
  digitalWrite(PIN_LEVEL_SELECT, config.use12V ? HIGH : LOW);
}

static void updateOutOfTapeSignal(void) {
  // Normally signal paper/tape available. This assumes the pin indicates out-of-tape,
  // so inactive means paper is available.
  writeConfiguredLevel(PIN_OUT_OF_TAPE, false, config.punch.dataActiveHigh);
}

// -----------------------------------------------------------------------------
// SD and configuration
// -----------------------------------------------------------------------------

static bool checkSdPresent(void) {
  // SD detect is active low and requires pull-up.
  return digitalRead(PIN_SD_DETECT) == LOW;
}

static bool beginSdFilesystem(void) {
  // Configure SPI pins for Arduino_Core_STM32 before starting SdFat.
  SPI.setSCLK(PA5);
  SPI.setMISO(PA6);
  SPI.setMOSI(PA7);
  SPI.begin();

  // Initialize the SD card and FAT filesystem using the selected chip select.
  return SD.begin(SdSpiConfig(PIN_SD_CS, DEDICATED_SPI, SD_SCK_MHZ(18), &SPI));
}


static void setDefaultConfig(void) {
  // Conservative defaults. These can be changed from the configuration menu.
  config.reader.commandActiveHigh = false;
  config.reader.ackPulseActiveHigh = false;
  config.reader.dataActiveHigh = true;

  config.punch.commandActiveHigh = false;
  config.punch.ackPulseActiveHigh = false;
  config.punch.dataActiveHigh = true;
  config.use12V = false;

  config.selectedReader[0] = ' ';
  config.selectedPunch[0] = '\0';
}

static void trimLine(char *s) {
  // Remove trailing CR/LF and spaces from a line read from the config file.
  size_t len = strlen(s);
  while (len > 0 && (s[len - 1] == '\r' || s[len - 1] == '\n' || s[len - 1] == ' ')) {
    s[len - 1] = '\0';
    len--;
  }
}

static bool parseBoolValue(const char *value) {
  // Accept common true values in the config file.
  return strcmp(value, "1") == 0 || strcasecmp(value, "true") == 0 || strcasecmp(value, "yes") == 0;
}

static void applyConfigKeyValue(const char *key, const char *value) {
  // Apply one key=value pair from the configuration file.
  if (strcmp(key, "reader.commandActiveHigh") == 0) config.reader.commandActiveHigh = parseBoolValue(value);
  else if (strcmp(key, "reader.ackPulseActiveHigh") == 0) config.reader.ackPulseActiveHigh = parseBoolValue(value);
  else if (strcmp(key, "reader.dataActiveHigh") == 0) config.reader.dataActiveHigh = parseBoolValue(value);
  else if (strcmp(key, "use12V") == 0) config.use12V = parseBoolValue(value);  // Backward compatibility with old config files
  else if (strcmp(key, "punch.commandActiveHigh") == 0) config.punch.commandActiveHigh = parseBoolValue(value);
  else if (strcmp(key, "punch.ackPulseActiveHigh") == 0) config.punch.ackPulseActiveHigh = parseBoolValue(value);
  else if (strcmp(key, "punch.dataActiveHigh") == 0) config.punch.dataActiveHigh = parseBoolValue(value);
  else if (strcmp(key, "selectedReader") == 0) strncpy(config.selectedReader, value, MAX_NAME_LEN - 1);
  else if (strcmp(key, "selectedPunch") == 0) strncpy(config.selectedPunch, value, MAX_NAME_LEN - 1);

  config.selectedReader[MAX_NAME_LEN - 1] = '\0';
  config.selectedPunch[MAX_NAME_LEN - 1] = '\0';
}

static void loadConfig(void) {
  // Load configuration from SD card, or create defaults if no config exists.
  setDefaultConfig();

  if (!sdPresent || !SD.exists(CONFIG_FILE)) {
    return;
  }

  File32 f = SD.open(CONFIG_FILE, FILE_READ);
  if (!f) return;

  char line[96];
  uint8_t pos = 0;

  while (f.available()) {
    char c = (char)f.read();
    if (c == '\n' || pos >= sizeof(line) - 1) {
      line[pos] = '\0';
      trimLine(line);
      char *eq = strchr(line, '=');
      if (eq != NULL) {
        *eq = '\0';
        applyConfigKeyValue(line, eq + 1);
      }
      pos = 0;
    } else {
      line[pos++] = c;
    }
  }

  if (pos > 0) {
    line[pos] = '\0';
    trimLine(line);
    char *eq = strchr(line, '=');
    if (eq != NULL) {
      *eq = '\0';
      applyConfigKeyValue(line, eq + 1);
    }
  }

  f.close();
}

static void saveConfig(void) {
  // Save configuration to SD card as simple key=value text.
  if (!sdPresent) return;

  SD.remove(CONFIG_FILE);
  File32 f = SD.open(CONFIG_FILE, FILE_WRITE);
  if (!f) return;

  f.print("reader.commandActiveHigh="); f.println(config.reader.commandActiveHigh ? "1" : "0");
  f.print("reader.ackPulseActiveHigh="); f.println(config.reader.ackPulseActiveHigh ? "1" : "0");
  f.print("reader.dataActiveHigh="); f.println(config.reader.dataActiveHigh ? "1" : "0");
  f.print("device.use12V="); f.println(config.use12V ? "1" : "0");

  f.print("punch.commandActiveHigh="); f.println(config.punch.commandActiveHigh ? "1" : "0");
  f.print("punch.ackPulseActiveHigh="); f.println(config.punch.ackPulseActiveHigh ? "1" : "0");
  f.print("punch.dataActiveHigh="); f.println(config.punch.dataActiveHigh ? "1" : "0");

  f.print("selectedReader="); f.println(config.selectedReader);
  f.print("selectedPunch="); f.println(config.selectedPunch);

  f.close();
}

static void ensureDirectory(const char *path) {
  // Create a directory if the SD library and card support it.
  if (!SD.exists(path)) {
    SD.mkdir(path);
  }
}

static void scanDirectory(const char *path, char files[][MAX_NAME_LEN], uint8_t &count) {
  // Read up to MAX_FILES regular file names from one directory.
  count = 0;

  File32 dir = SD.open(path);
  if (!dir) return;

  while (count < MAX_FILES) {
    File32 entry = dir.openNextFile();
    if (!entry) break;

    if (!entry.isDirectory()) {
      // VictorPV/SdFat uses getName() instead of name().
      entry.getName(files[count], MAX_NAME_LEN);

      // Make extra sure the string is terminated.
      files[count][MAX_NAME_LEN - 1] = '\0';

      count++;
    }

    entry.close();
  }

  dir.close();
}

static void scanFiles(void) {
  // Ensure folders exist and refresh reader/punch file lists.
  if (!sdPresent) {
    readerFileCount = 0;
    punchFileCount = 0;
    return;
  }

  ensureDirectory(TAPE_DIR);
  scanDirectory(TAPE_DIR, readerFiles, readerFileCount);
  scanDirectory(TAPE_DIR, punchFiles, punchFileCount);
}

static void buildPath(char *out, size_t outSize, const char *dir, const char *name) {
  // Build a simple /dir/name path.
  snprintf(out, outSize, "%s/%s", dir, name);
}

static void closeTapeFiles(void) {
  // Close open files before changing mode, SD removal, or USB MSC entry.
  if (readerFile) readerFile.close();
  if (punchFile) punchFile.close();
}

static void openSelectedFiles(void) {
  // Open selected reader and punch files for emulator operation.
  closeTapeFiles();

  if (!sdPresent) return;

  char path[80];

  if (config.selectedReader[0] != '\0') {
    buildPath(path, sizeof(path), TAPE_DIR, config.selectedReader);
    readerFile = SD.open(path, FILE_READ);
  }

  if (config.selectedPunch[0] != '\0') {
    buildPath(path, sizeof(path), TAPE_DIR, config.selectedPunch);
    punchFile = SD.open(path, FILE_WRITE);
    if (punchFile) {
      punchFile.seek(punchFile.size());
    }
  }
}

static bool reopenReaderFromBeginning(void) {
  // Re-open the selected reader tape from byte 0.
  // This is used as a "rewind tape" action from a long DOWN press.
  if (readerFile) {
    readerFile.close();
  }



  prepareReaderBusIdle();

  if (!sdPresent || config.selectedReader[0] == '\0') {
    DBG_PRINTLN("Reader rewind failed: no SD card or no reader file selected");
    return false;
  }

  char path[80];
  buildPath(path, sizeof(path), TAPE_DIR, config.selectedReader);

  readerFile = SD.open(path, FILE_READ);
  if (!readerFile) {
    DBG_PRINT("Reader rewind failed: ");
    DBG_PRINTLN(path);
    return false;
  }

  DBG_PRINT("Reader rewound: ");
  DBG_PRINTLN(path);
  return true;
}

static bool createNewPunchFile(void) {
  // Create PUNCHnnn.BIN using the first available sequence number.
  if (!sdPresent) return false;

  char name[MAX_NAME_LEN];
  char path[80];

  for (uint16_t n = 0; n < 1000; n++) {
    snprintf(name, sizeof(name), "PUNCH%03u.BIN", n);
    buildPath(path, sizeof(path), TAPE_DIR, name);

    if (!SD.exists(path)) {
      File32 f = SD.open(path, FILE_WRITE);
      if (!f) return false;
      f.close();

      strncpy(config.selectedPunch, name, MAX_NAME_LEN - 1);
      config.selectedPunch[MAX_NAME_LEN - 1] = '\0';
      saveConfig();
      scanFiles();
      openSelectedFiles();
      return true;
    }
  }

  return false;
}

// -----------------------------------------------------------------------------
// USB MSC adapter hooks
// -----------------------------------------------------------------------------


static bool usbMscStart(void) {
  // Enter USB mass-storage mode. The SD card must no longer be used by the
  // paper tape emulator while the host computer owns it as a USB disk.
  if (!sdPresent) return false;
  if (digitalRead(PIN_USB_VBUS) == LOW) return false;

  closeTapeFiles();
  emulatorEnabled = false;

  // Make sure all local filesystem writes are committed before MSC starts.
  SD.card()->syncDevice();

  usbMscSectorCount = SD.card()->sectorCount();
  if (usbMscSectorCount == 0) {
    return false;
  }

  // Configure the MSC device once. Later mode switches only toggle unit-ready
  // and the external USB connect circuit on PA3.
  if (!usbMscConfigured) {
    usb_msc.setID("HP21XX", "PaperTapeSD", "1.0");
    usb_msc.setReadWriteCallback(usbMscReadCallback, usbMscWriteCallback, usbMscFlushCallback);
    usb_msc.setCapacity(usbMscSectorCount, 512);
    usb_msc.setUnitReady(false);
    usb_msc.begin();
    usbMscConfigured = true;
  } else {
    // Re-apply capacity in case the card changed while USB was disabled.
    usb_msc.setCapacity(usbMscSectorCount, 512);
  }

  usbMscReadCount = 0;
  usbMscWriteCount = 0;

  // Pull up PA3 to enable the external USB connect circuit described in the spec.
  digitalWrite(PIN_USB_PULLUP, HIGH);
  delay(100);

  // Now allow the host to access the medium.
  usb_msc.setUnitReady(true);

  usbMscEnabled = true;
  uiMode = UI_USB_MSC;
  return true;
}

static void usbMscStop(void) {
  // Stop USB MSC and return control of the SD card to the emulator.
  // The user should eject/unmount on the host before doing this.
  usb_msc.setUnitReady(false);
  delay(300);

  // Physically disconnect USB from the host.
  digitalWrite(PIN_USB_PULLUP, LOW);
  delay(300);

  usbMscEnabled = false;
  usbMscSectorCount = 0;
  uiMode = UI_MAIN;

  // Re-mount the filesystem view after the host has released the card.
  if (sdPresent) {
    beginSdFilesystem();
  }

  scanFiles();
  openSelectedFiles();
  emulatorEnabled = sdPresent;
}

// -----------------------------------------------------------------------------
// Paper tape emulator
// -----------------------------------------------------------------------------

static void prepareReaderBusIdle(void) {
  // Idle with the external host-to-device buffer disabled to avoid bus contention.
  digitalWrite(PIN_BUS_DIR, HIGH);
  setDataBusInput();
}

static void serviceReader(void) {
  bool cmdActive = isActive(digitalRead(PIN_READER_CMD) == HIGH,
                            config.reader.commandActiveHigh);
  
  DBG_PRINT("A");
  DBG_PRINT(cmdActive);
  /*if (readerWaitingForRelease) {
    DBG_PRINT("B");
    if (!cmdActive) {
      DBG_PRINT("C");
      readerWaitingForRelease = false;
      prepareReaderBusIdle();
    }
    return;
  }*/
  DBG_PRINT("D");
  if (!cmdActive) return;
  DBG_PRINT("H");
  if (!readerFile) return;
  DBG_PRINT("E");
  digitalWrite(PIN_BUS_DIR, HIGH);
  setDataBusOutput();

  int b = readerFile.read();

  if (b < 0) {
    DBG_PRINT("F");
    // if run out we return 0xff as if there is no tape at all!
    b=0xff;
  }
  DBG_PRINT("=");
  DBG_PRINT(b);
  DBG_PRINT("*");
  writeDataBus((uint8_t)b, config.reader.dataActiveHigh);
  pulseAck(PIN_READER_ACK, config.reader.ackPulseActiveHigh);
  blinkActivity();

  DBG_PRINT("G");
}

static void servicePunch(void) {
  bool cmdActive = isActive(digitalRead(PIN_PUNCH_CMD) == HIGH,
                            config.punch.commandActiveHigh);


  if (!cmdActive || !punchFile) return;
  setDataBusInput();
  digitalWrite(PIN_BUS_DIR, LOW);

  uint8_t b = readDataBus(config.punch.dataActiveHigh);
  punchFile.write(b);
  //punchFile.flush();
  //delayMicroseconds(5);
  pulseAck(PIN_PUNCH_ACK, config.punch.ackPulseActiveHigh);
  blinkActivity();
}

static void serviceTapeEmulator(void) {
  // The emulator is disabled while USB MSC owns the SD card.
  if (!emulatorEnabled || usbMscEnabled || !sdPresent) return;

  serviceReader();
  servicePunch();
}

// -----------------------------------------------------------------------------
// UI helpers
// -----------------------------------------------------------------------------
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
void loop(void) {
  // Stop SD-using functions immediately if the card is removed.
  bool nowSdPresent = checkSdPresent();
  if (nowSdPresent != sdPresent) {
    sdPresent = nowSdPresent;

    if (!sdPresent) {
      closeTapeFiles();
      emulatorEnabled = false;
      if (usbMscEnabled) usbMscStop();
    } else {
      beginSdFilesystem();
      loadConfig();
      scanFiles();
      openSelectedFiles();
      emulatorEnabled = !usbMscEnabled;
    }

    redrawUi();
  }

  serviceButtons();
  serviceActivityLed();

  if (!usbMscEnabled) {
    serviceTapeEmulator();
  } else {
    // Some STM32 TinyUSB ports auto-poll internally. If your installed port
    // requires manual polling, uncomment the matching line below.
    // TinyUSBDevice.task();
    // tud_task();
  }
  //delayMicroseconds(10000);
}

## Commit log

2026-01-11 Added schematics.
    [hp21xx_papertape_emulator.kicad_pcb, hp21xx_papertape_emulator.kicad_sch]
2026-01-11 Add STM32F103C8 Paper Tape Emulator code
    This commit introduces the STM32F103C8 Paper Tape Emulator for HP 12566, implementing USB MSC and SD card functionalities. Key updates include pin configurations for USB pull-up and SD card detection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
2026-01-16 Tried to create production files but it failed...
    [BOM-hp21xx_papertape_emulator.csv, bom.csv, designators.csv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]
2026-01-17 Almost done. Waiting for confirming OLED display and buttons dimensions.
    [BOM-hp21xx_papertape_emulator.csv, hp21xx_papertape_emulator.kicad_pcb, hp21xx_papertape_emulator.kicad_sch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]
2026-01-19 Added paper out handling.
    [hp21xx_papertape_emulator.kicad_pcb, hp21xx_papertape_emulator.kicad_sch]
2026-01-23 Updates to support simultaneous PTR and PTP. Able yo use 540 and 541 instead of 245 if not available.
    [hp21xx_papertape_emulator.kicad_pcb, hp21xx_papertape_emulator.kicad_sch]
2026-01-24 Updated to use NMOS drivers instead.
    [hp21xx_papertape_emulator.kicad_sch]
2026-01-25 Removed the enable function since it wasn't a good idea.
    [hp21xx_papertape_emulator.kicad_sch]
2026-01-29 New drivers.
    [BOM-hp21xx_papertape_emulator.csv, hp21xx_papertape_emulator.kicad_pcb, hp21xx_papertape_emulator.kicad_sch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]
2026-01-30 Fixed issues.
    [hp21xx_papertape_emulator.kicad_pcb, hp21xx_papertape_emulator.kicad_sch]
2026-01-30 Fixed problems with net unconnected.
    [BOM-hp21xx_papertape_emulator.csv, hp21xx_papertape_emulator.kicad_pcb, hp21xx_papertape_emulator.kicad_sch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]
2026-03-04 spin 2
    [BOM-hp21xx_papertape_emulator.csv, hp21xx_papertape_emulator.kicad_pcb, hp21xx_papertape_emulator.kicad_sch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]
2026-03-21 Fixed new spin.
    [BOM-hp21xx_papertape_emulator.csv, hp21xx_papertape_emulator.kicad_pcb, hp21xx_papertape_emulator.kicad_sch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]
2026-03-23 Fixed missing LCSC number for BAT54
    [BOM-hp21xx_papertape_emulator.csv, hp21xx_papertape_emulator.kicad_pcb, hp21xx_papertape_emulator.kicad_sch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]
2026-06-02 Fixing so that it isn't locking up. Adding debuging
    Fixing so that it isn't locking up. Adding debuging
    [hp21xx_papertape_emulator.ino]
2026-06-12 Enhance README with detailed emulator information
    Expanded the README with detailed information about the emulator's UI, BOM, connectors, and modifications for supplying 5V.
2026-06-12 Add project progress details and media links to README
    Added a progress section detailing the current capabilities of the project, including reading and punching files. Included a video link and images of the finished board.
2026-06-12 Update README with connector pin mappings
    Added detailed pin mapping for 26 pin to 48 pin connectors for both reader and punch components.
2026-06-12 Revise pin connection details in README
    Updated pin mapping details for 12566 and 12597 boards, including designators and modifications.
2026-06-12 Add documentation section to README
    Added documentation links for HP 12597 and 12566 boards.
2026-06-12 Clarify pin descriptions in README.md
2026-06-14 Document firmware setup and requirements
    Added firmware section detailing the Arduino framework and STM32 setup.
2026-06-15 Update README with boot mode instructions and details
    Clarified instructions for entering serial boot mode and updated details about the BOOT1 pin.
2026-06-16 Added jumper to be able to use serial bootstrap mode.
    [hp21xx_papertape_emulator.kicad_pcb, hp21xx_papertape_emulator.kicad_sch]
2026-06-16 Added Arduino config picture
2026-08-22 Fix errors in pin connection table in README
    Corrected errors in the pin connection table for the 26 pin and 48 pin connectors. Updated the order and content of the entries for clarity.
2026-08-24 Fix typo in cable verification note
    Corrected a typo in the README regarding cable verification.
2026-11-04 Added CAD design for a box
2026-11-04 Add enclosure section to README
    Added a section about the enclosure and its design process using Codex.
2026-11-08 V2.0 using big SD card. Reset button.
2026-11-08 V2.0 using big SD card. Reset button. Fixed enclosure.
